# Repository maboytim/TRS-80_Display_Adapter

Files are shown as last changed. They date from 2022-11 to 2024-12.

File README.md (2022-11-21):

# TRS-80_Display_Adapter
Display board and CRT replacement for TRS-80 Models 3 and 4 and the big Tandy's.

### Overview

The adapter board connects to where the the display board normally connects.  It converts the video signals to HDMI or VGA so a modern monitor can be used instead of the builtin CRT.  The adapter uses a low cost (~$15) Nano-9k FPGA module.

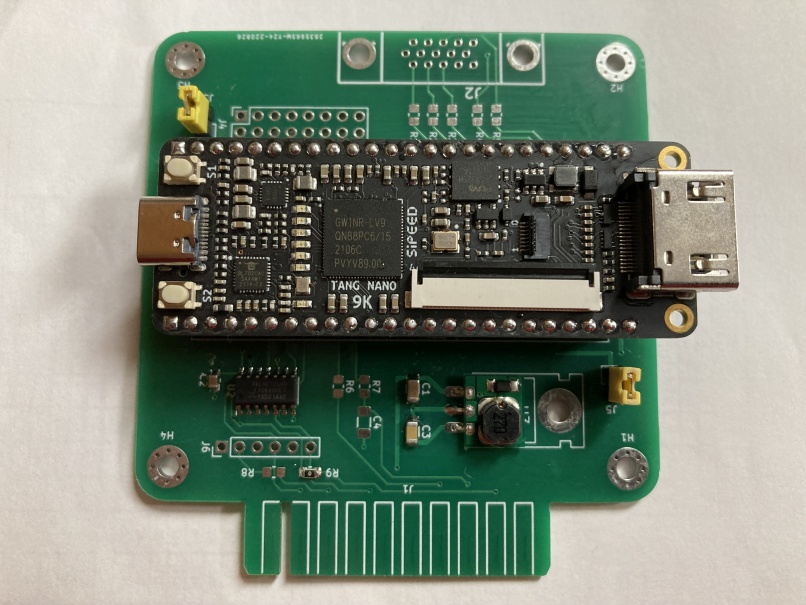
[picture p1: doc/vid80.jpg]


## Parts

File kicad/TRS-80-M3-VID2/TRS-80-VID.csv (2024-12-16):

Reference | Value | Description | Comment
C1 | 10u | 1206
C2 | 0.1uF | 0805
C3 | 1u | 1206
C4 | 1u | 1206 | DNP
J2 | VGA | DB15_Female_HighDensity | Only for VGA out - DMP otherwise.
J3 | 1x2 header |  | Test jumper
J4 | 2x8 header |  | Optional
J5 | 1x2 header | Place shorting block for 5V power from regulator, remove if connecting to USB.
J6 | 1x6 header | For direct cable connection - DNP if not used.
R1 | 200 | 0805 | Only for VGA out - DNP otherwise.
R2 | 200 | 0805 | Only for VGA out - DNP otherwise.
R3 | 200 | 0805 | Only for VGA out - DNP otherwise.
R4 | 200 | 0805 | Only for VGA out - DNP otherwise.
R5 | 200 | 0805 | Only for VGA out - DNP otherwise.
R6 | 1k | 0805 | DNP
R7 | 1k | 0805 | DNP
R8 | 0 | 0805 | Place either R8 or R9 to connect video signal.
R9 | 0 | 0805 | Place either R9 or R8 to connect video signal.
U1 | Tango_Nano_9K
U1 | 24 pin SIP socket | https://www.amazon.com/gp/product/B07GNZQ3ZY or equivalent | Cut to length.
U2 | SO14 | 74LVC125
U3 | L7805 | Regulator | With suitable heatsink. DC-DC converter recommended instead.
U3 | Digikey K7805-500R3-LB | DC-DC replacement for 7805.

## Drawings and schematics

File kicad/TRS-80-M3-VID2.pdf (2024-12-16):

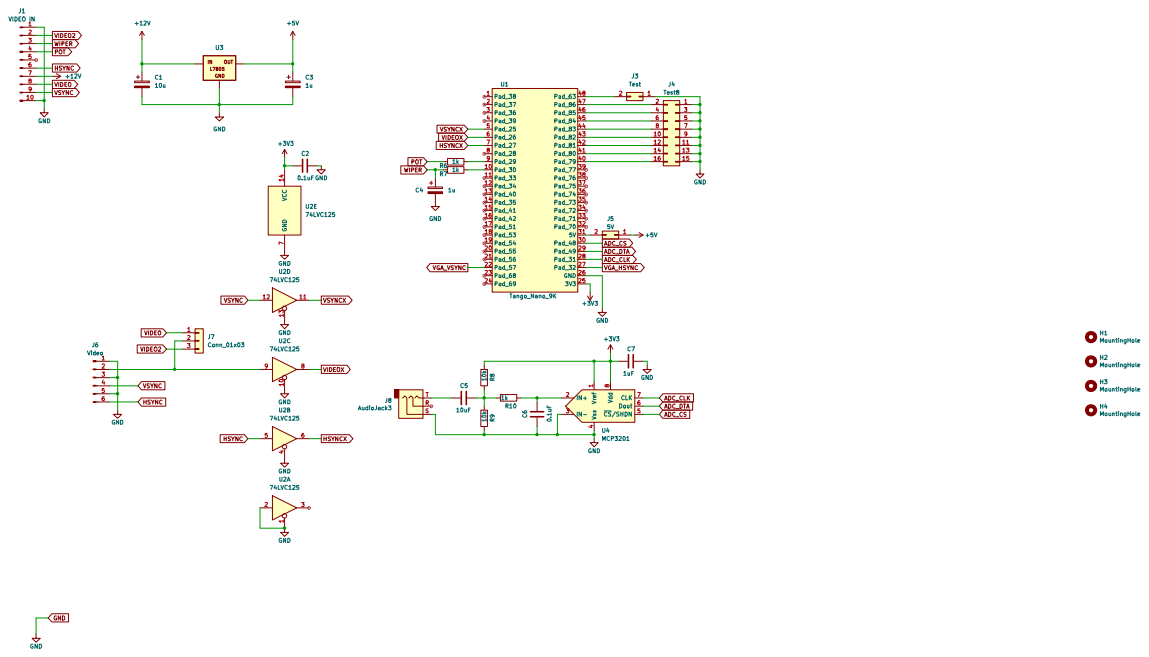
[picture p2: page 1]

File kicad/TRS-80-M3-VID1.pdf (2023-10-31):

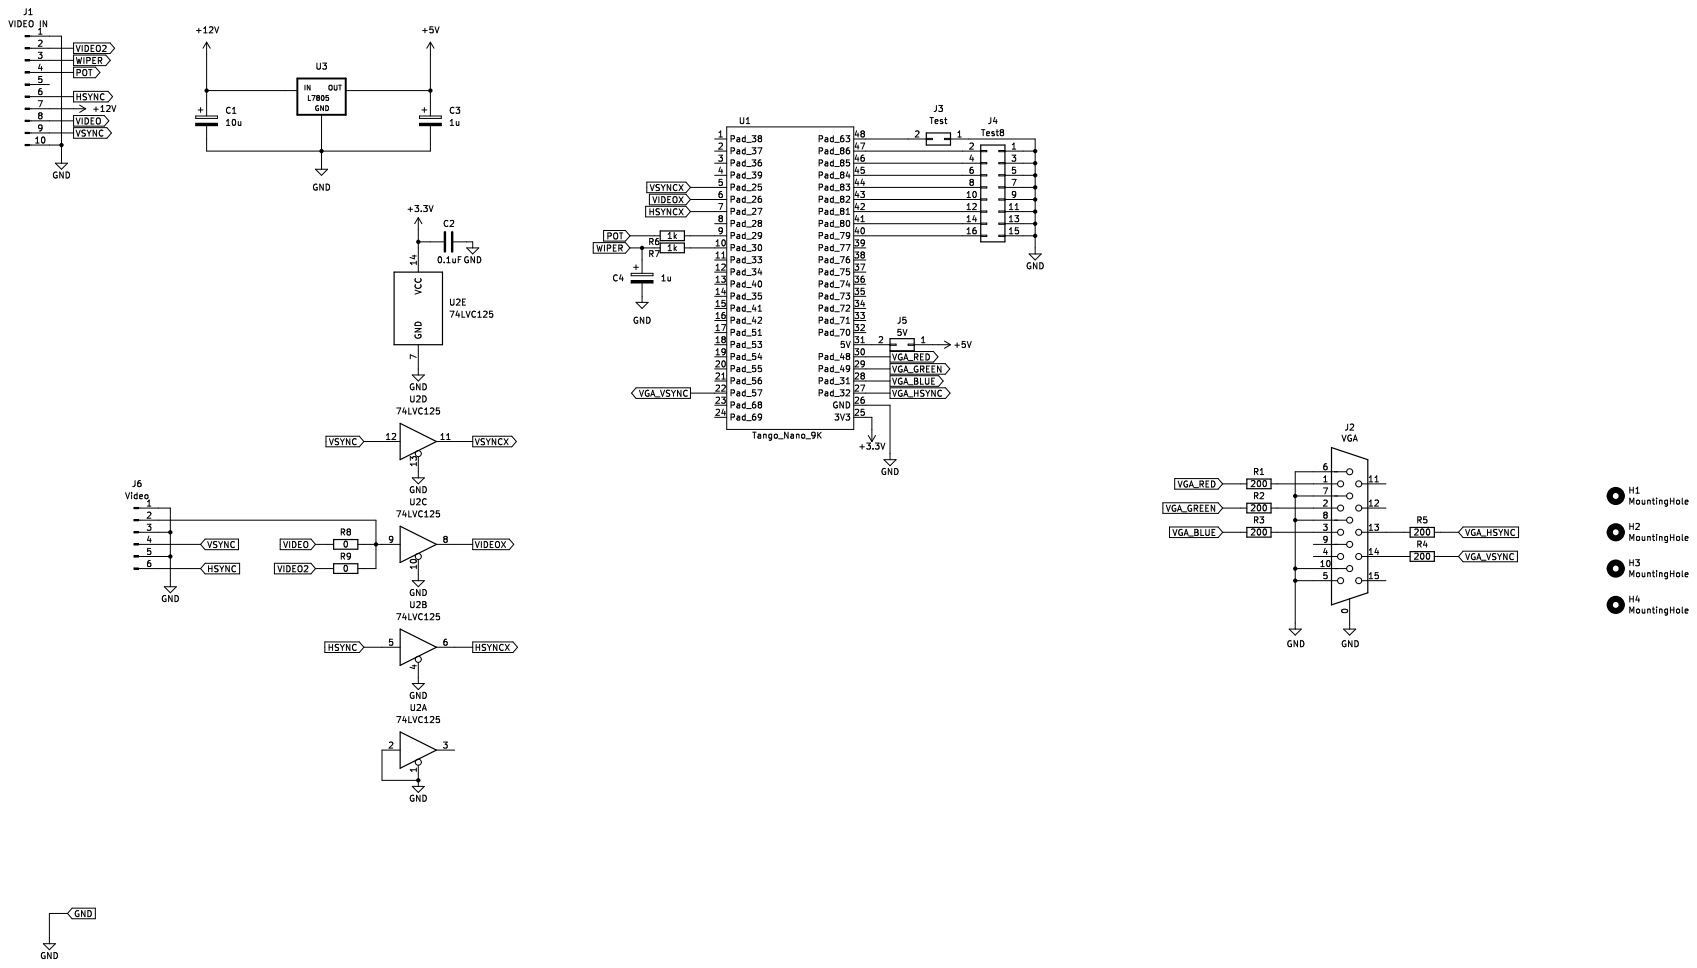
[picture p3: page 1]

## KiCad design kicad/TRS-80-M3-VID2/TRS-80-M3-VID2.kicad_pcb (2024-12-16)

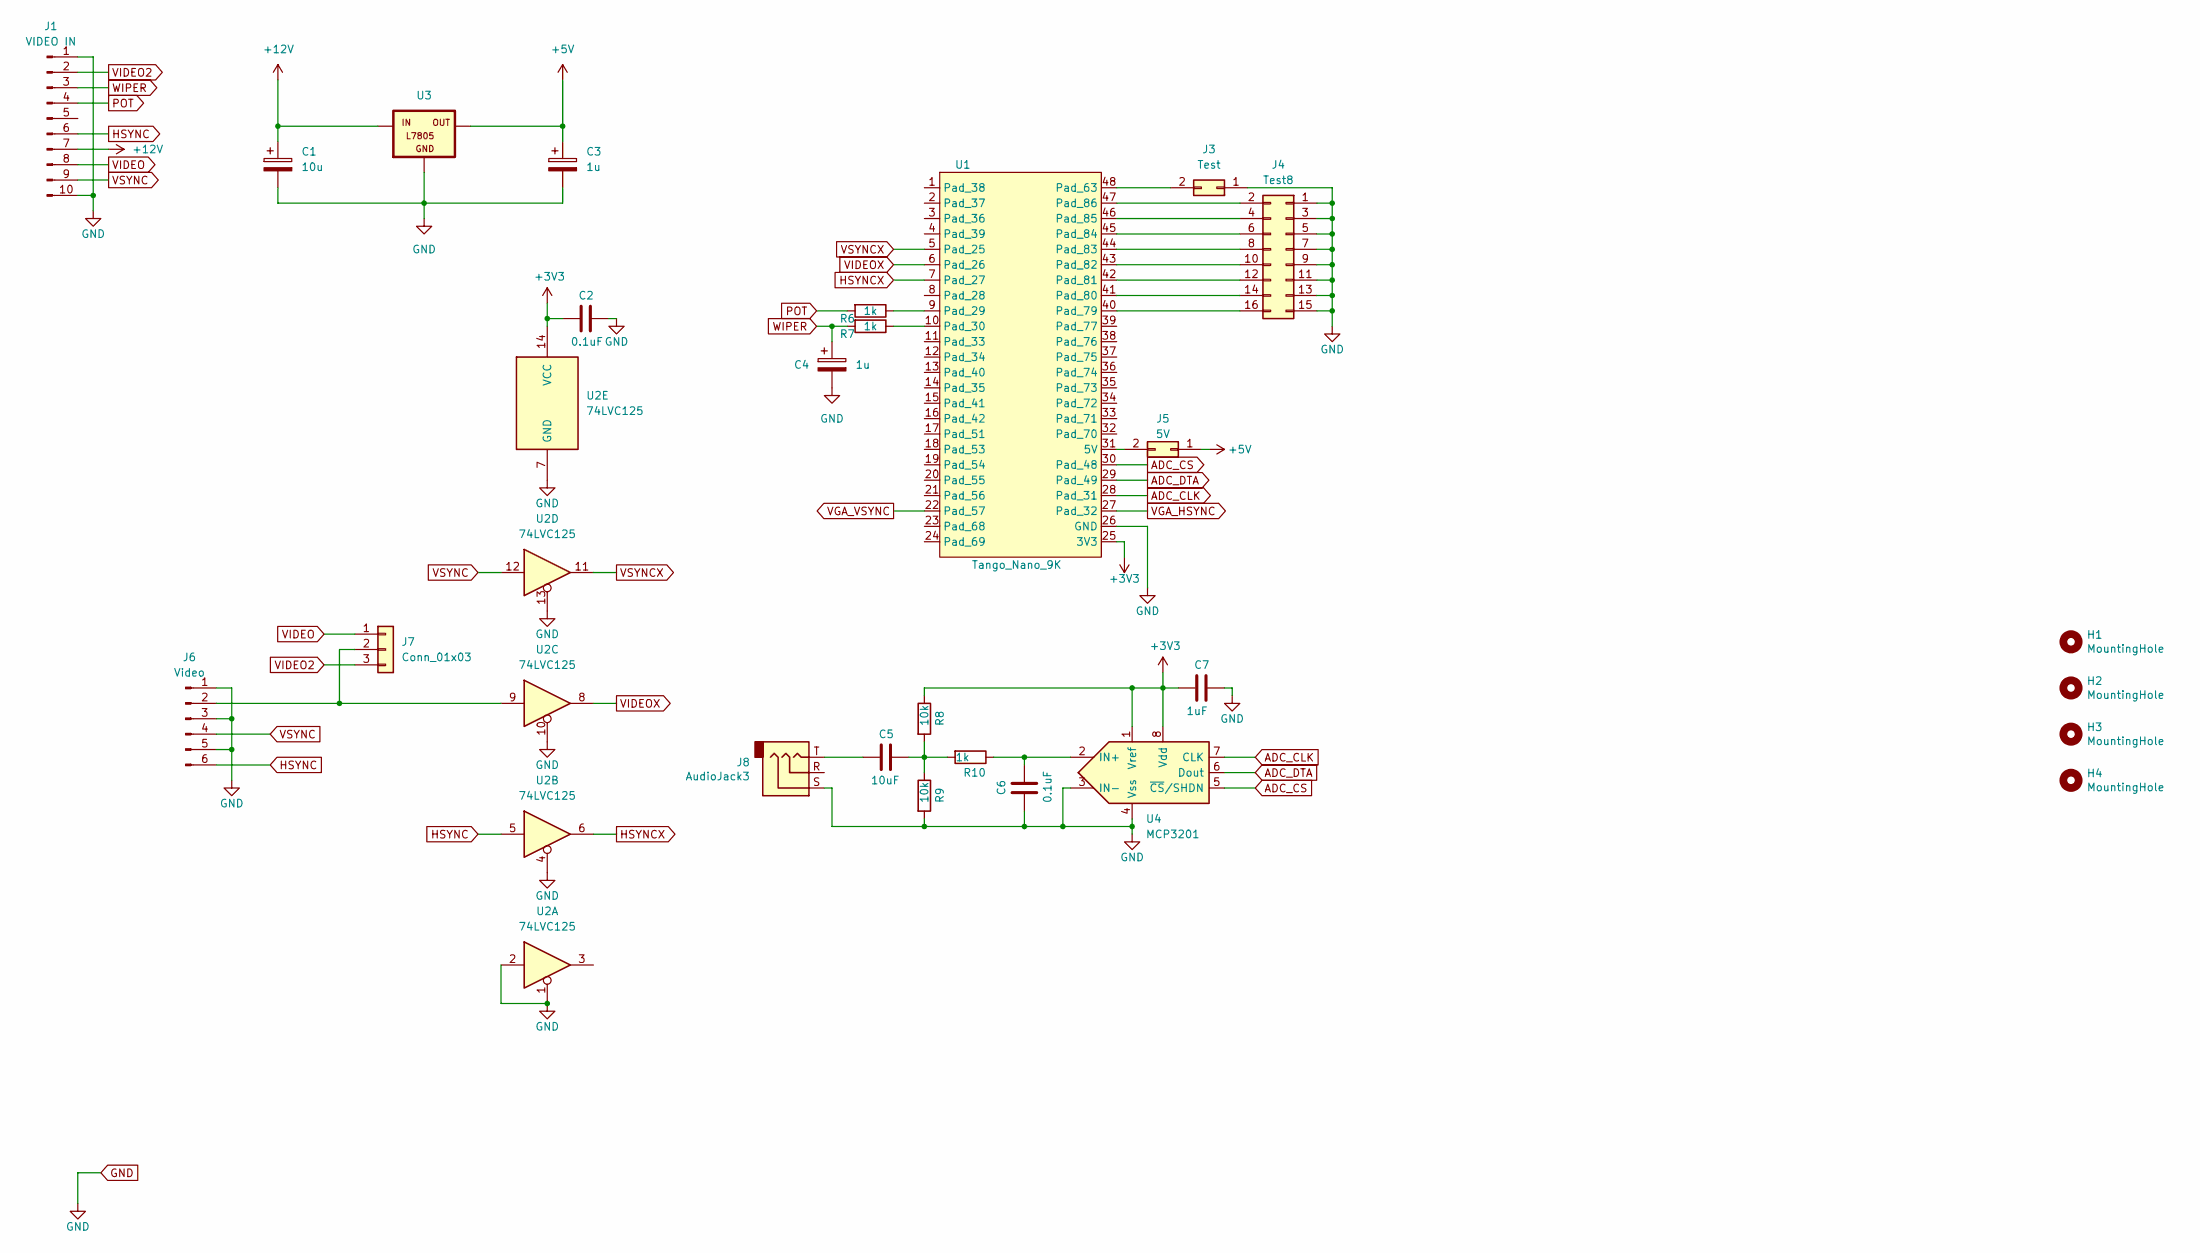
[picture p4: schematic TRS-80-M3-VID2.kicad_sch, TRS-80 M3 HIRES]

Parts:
C1: 10u; C_1206_3216Metric_Pad1.33x1.80mm_HandSolder
C2, C6: 0.1uF; C_0805_2012Metric_Pad1.18x1.45mm_HandSolder
C3, C4: 1u; C_1206_3216Metric_Pad1.33x1.80mm_HandSolder
C5: 10uF; C_0805_2012Metric_Pad1.18x1.45mm_HandSolder
C7: 1uF; C_0805_2012Metric_Pad1.18x1.45mm_HandSolder
H1, H2, H3, H4: MountingHole; MountingHole_3mm_Pad_Via
J1: VIDEO IN; TRSVID10
J3: Test; PinHeader_1x02_P2.54mm_Vertical
J4: Test8; PinSocket_2x08_P2.54mm_Vertical
J5: 5V; PinHeader_1x02_P2.54mm_Vertical
J6: Video; PinHeader_1x06_P2.54mm_Vertical
J7: Conn_01x03; PinHeader_1x03_P2.54mm_Vertical
J8: AudioJack3; Jack_3.5mm_CUI_SJ1-3535NG_Horizontal
R6, R7, R10: 1k; R_0805_2012Metric_Pad1.20x1.40mm_HandSolder
R8, R9: 10k; R_0805_2012Metric_Pad1.20x1.40mm_HandSolder
U1: Tango_Nano_9K; DIP-48_W22.9mm
U2: 74LVC125; SO-14_3.9x8.65mm_P1.27mm
U3: L7805; 78XXL
U4: MCP3201; SOIC-8_3.9x4.9mm_P1.27mm

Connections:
+3V3: C2.2, C7.2, R8.1, U1.25 (3V3), U2.14 (VCC), U4.1 (Vref), U4.8 (Vdd)
+5V: C3.1, J5.1, U3.OUT
+12V: C1.1, J1.7, U3.IN
ADC_CLK: U1.28 (Pad_31), U4.7 (CLK)
ADC_CS: U1.30 (Pad_48), U4.5 (~CS/SHDN)
ADC_DTA: U1.29 (Pad_49), U4.6 (Dout)
GND: C1.2, C2.1, C3.2, C4.2, C6.2, C7.1, J1.1, J1.10, J3.1, J4.1, J4.3, J4.5, J4.7, J4.9, J4.11, J4.13, J4.15, J6.1, J6.3, J6.5, J8.S, R9.2, U1.26 (GND), U2.1, U2.2, U2.4, U2.7 (GND), U2.10, U2.13, U3.GND, U4.3 (IN-), U4.4 (Vss)
HSYNC: J1.6, J6.6, U2.5
HSYNCX: U1.7 (Pad_27), U2.6
unnamed: C5.1, R8.2, R9.1, R10.2
unnamed: C5.2, J8.T
unnamed: J3.2, U1.48 (Pad_63)
unnamed: J4.2, U1.47 (Pad_86)
unnamed: J4.4, U1.46 (Pad_85)
unnamed: J4.6, U1.45 (Pad_84)
unnamed: J4.8, U1.44 (Pad_83)
unnamed: J4.10, U1.43 (Pad_82)
unnamed: J4.12, U1.42 (Pad_81)
unnamed: J4.14, U1.41 (Pad_80)
unnamed: J4.16, U1.40 (Pad_79)
unnamed: J5.2, U1.31 (5V)
unnamed: J6.2, J7.2, U2.9
unnamed: R6.1, U1.9 (Pad_29)
unnamed: R7.1, U1.10 (Pad_30)
unnamed: C6.1, R10.1, U4.2 (IN+)
POT: J1.4, R6.2
VGA_HSYNC: U1.27 (Pad_32)
VGA_VSYNC: U1.22 (Pad_57)
VIDEO: J1.8, J7.1
VIDEO2: J1.2, J7.3
VIDEOX: U1.6 (Pad_26), U2.8
VSYNC: J1.9, J6.4, U2.12
VSYNCX: U1.5 (Pad_25), U2.11
WIPER: C4.1, J1.3, R7.2

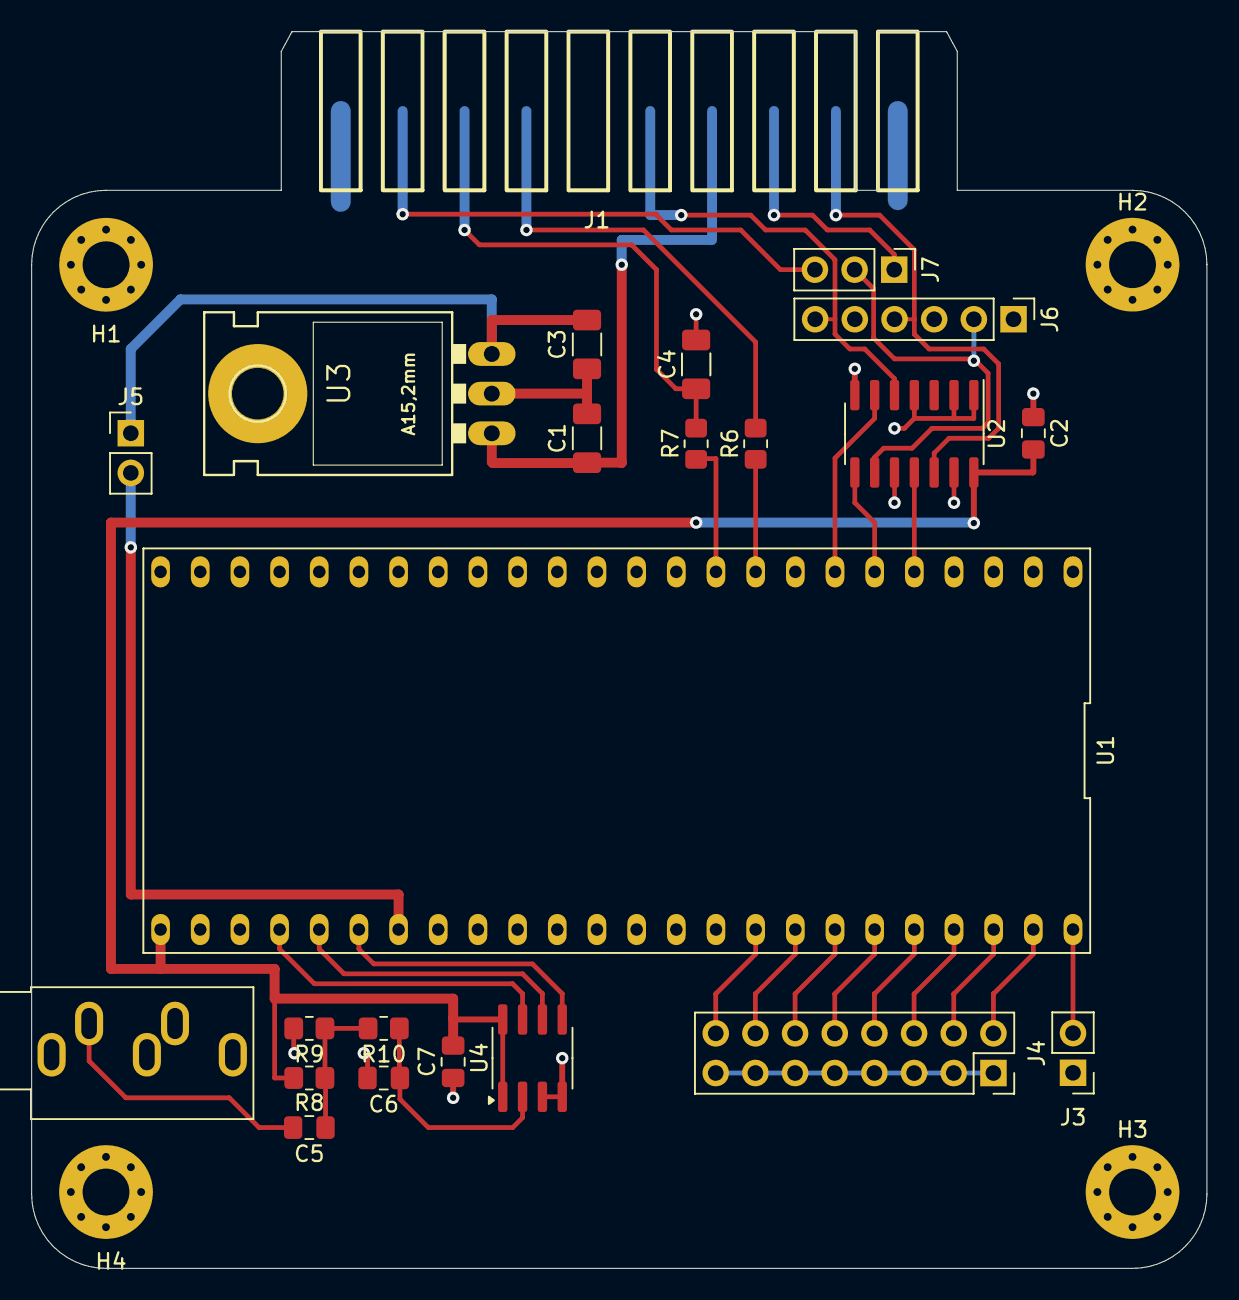
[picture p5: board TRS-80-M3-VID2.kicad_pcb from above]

Board: 2 copper layers, 75.2 x 79.2 mm, 27 parts (0 on the bottom side), 32 nets.

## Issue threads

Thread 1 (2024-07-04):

Video text color

telanoc, 2024-07-04:
It would be incredibly nice if maybe one or two pairs on the row of jumpers was put to use to give green or amber video.  It's the only thing I can think of that might be "wrong" with your board.  Is there room in the chip for such a thing?

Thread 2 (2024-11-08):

Verilog compilation issues

arch-linux, 2024-11-08:
Hello! @maboytim,

I had the boards made, and I am attempting to write the FPGA, I am using VSCODE to compile your FPGA code.

Using this guide [here](https://learn.lushaylabs.com/getting-setup-with-the-tang-nano-9k/)

I am having issues compiling due to a few issues. I am getting the feeling maybe you used a different toolkit or different software entirely for this.

`Processing vis80.lushay.json
Starting FPGA Toolchain
Starting Yosys CST Checking
     /----------------------------------------------------------------------------\
     |  yosys -- Yosys Open SYnthesis Suite                                       |
     |  Copyright (C) 2012 - 2024  Claire Xenia Wolf <claire@yosyshq.com>         |
     |  Distributed under an ISC-like license, type "license" to see terms        |
     \----------------------------------------------------------------------------/
    Parsing gowin_clkdiv.v
        - Module Gowin_CLKDIV parsed
    Parsing gowin_dpb.v
        - Module Gowin_DPB parsed
    Parsing gowin_rpll.v
        - Module Gowin_rPLL parsed
    Parsing BUFG.v
        - Module BUFG parsed
    Error: /Users/archlinuxusa/Downloads/TRS-80_Display_Adapter-main/fpga/vid80-3/src/top.v:47: ERROR: syntax error, unexpected ';', expecting '(' or '['
    Check lines 46-47 of file top.v you may be missing a semicolon or left a block open
Finished CST Checking
Task finished with errors exiting
Toolchain Completed
`

Could you share what you used to program the TANG Nano 9k?
Did you use the VSCODE Chain of tools or  GOWIN?

Thank you very much.

maboytim, 2024-11-09:
Hi,
I use the Gowin IDE.  I've not tried the open source tools.
There are two versions of the Gowin IDE - a full version and a free educational version.  I use the free educational version.
From your errors it looks like the compiler is having trouble with the Gowin IP blocks.  Since I don't know the open source tools I can't help you with that but you might ask someone in that community for help.  These blocks are really hard IP's to access resources on the chip like PLL's and BRAMs.
You shouldn't have to compile though unless you want to make changes.  The .fs programming file is in the impl/pnr folder which is all you really need.  I have used the openFPGALoader which works.  There is also a standalone programmer available from Gowin.  You can program to SRAM but that is volatile and will be lost if you cycle power.  To be persistent you need to program the embedded flash.
If you have any problems feel free to email me directly at ***@***.***
Matt

    On Friday, November 8, 2024 at 06:06:06 PM EST, Christopher Allen ***@***.***> wrote:

Hello! @maboytim,

I had the boards made, and I am attempting to write the FPGA, I am using VSCODE to compile your FPGA code.

Using this guide here

I am having issues compiling due to a few issues. I am getting the feeling maybe you used a different toolkit or different software entirely for this.

Processing vis80.lushay.json Starting FPGA Toolchain Starting Yosys CST Checking /----------------------------------------------------------------------------\ | yosys -- Yosys Open SYnthesis Suite | | Copyright (C) 2012 - 2024 Claire Xenia Wolf ***@***.***> | | Distributed under an ISC-like license, type "license" to see terms | \----------------------------------------------------------------------------/ Parsing gowin_clkdiv.v - Module Gowin_CLKDIV parsed Parsing gowin_dpb.v - Module Gowin_DPB parsed Parsing gowin_rpll.v - Module Gowin_rPLL parsed Parsing BUFG.v - Module BUFG parsed Error: /Users/archlinuxusa/Downloads/TRS-80_Display_Adapter-main/fpga/vid80-3/src/top.v:47: ERROR: syntax error, unexpected ';', expecting '(' or '[' Check lines 46-47 of file top.v you may be missing a semicolon or left a block open Finished CST Checking Task finished with errors exiting Toolchain Completed

Could you share what you used to program the TANG Nano 9k?
Did you use the VSCODE Chain of tools or GOWIN?

Thank you very much.

—
Reply to this email directly, view it on GitHub, or unsubscribe.
You are receiving this because you were mentioned.Message ID: ***@***.***>

arch-linux, 2024-11-09:
@maboytim
Myth Confirmed!

After following your info, I got this going and it works flawlessly.
Thank you very much.

I have 9 other boards that I could potentially populate and produce. Before making any decisions, I wanted to confirm with your unlicense in the github that there are no issues with me selling the remaining PCBs. I want to respect your hard work.

Its also acceptable if you want to speak about this over email - let me know and ill provide mine.

Respectfully

maboytim, 2024-11-13:
I think when you create a project github makes you pick a license.  I tried to pick the most permissive license.  I certainly appreciate your concern of the developer but all of my projects are completely free to do with whatever you want with no credit to me whatsoever.  I'm glad you got it working.  Try PM'ing me for my email.
Matt
    On Friday, November 8, 2024 at 08:54:35 PM EST, Christopher Allen ***@***.***> wrote:

@maboytim
Myth Confirmed!

After following your info, I got this going and it works flawlessly.
Thank you very much.

I have 9 other boards that I could potentially populate and produce. Before making any decisions, I wanted to confirm with your unlicense in the github that there are no issues with me selling the remaining PCBs. I want to respect your hard work.

Its also acceptable if you want to speak about this over email - let me know and ill provide mine.

Respectfully

—
Reply to this email directly, view it on GitHub, or unsubscribe.
You are receiving this because you were mentioned.Message ID: ***@***.***>

Closed 2024-11-10.

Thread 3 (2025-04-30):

Model 1 Support

kiwisincebirth, 2025-04-30:
Would it be possible to adapt this to a TRS-80 Model 1 Computer. Basically a model 1 shares a very similar video display. The primary difference I understand is the DOT clock is lower on the Model 1 since the raster size is 384 / 192, compared to 512 / 192 on the model 3. but the majority of the video circuitry (and signals) are the same.

Apart from maybe a slightly more generic board design. What would it take from a software perspective?

kiwisincebirth, 2025-04-30:
I take it all back I just spotted that you have introduced some support for this. Just didnt see it on the main readme.doc.

maboytim, 2025-05-01:
Besides the resolution the main difference is the M1 video is composite which requires a sync separator to obtain the sync signals.  The M1 sync's are generated using some 74C chips which are used essentially as analog circuits consequently the M1 video isn't real stable.  Consequently it's better to get the sync's directly from the digital circuits.  The M1 video connector conveniently has two unused pins that you can jumper the syncs to.  My idea then was to make a small PCB that buffers the signals and outputs them on a 6-pin connector that's directly compatible with the 6-pin connector on the video adapter board.  I thought I designed the interface board but I don't see it in my kicad folder.  I will do it in the next few days and order it from Oshpark.

kiwisincebirth, 2025-05-01:
Thanks for the response. I came across the project when i was searching for a way to improve the output of my custom built Model 1 - https://github.com/kiwisincebirth/TRS-80-MODEL-1-K/tree/main

It is based on the Japanese Model 1, which has a quite different video generation. (a) The timing dividers have been improved to correctly handle the PAL region (which i live) 625 lines/frame 50Hz, by adding additional lines in the vertical blanking interval. (b) the hsync/vsync generation (original rc delay line with trimpots) has been replaced with digital logic based on the counters eliminating all the horizontal instability.

Unfortunately due to availability I have used a 10.700 Mhz main crystal, so this introduces a .5% variance.  In practice I have found the video output to be rock steady, but the generic Amazon composite to HDMI adapter doesn't do a great job and you are just left with a fuzzy image. A modern TV does a better job but the image if off centre (to right) which is quite annoying, and I am not inclined to use this in front of a large TV

I am not sure how easily it would be to adapt to my build, I haven't done any FPGA development which is probably the limiting factor.

(And off topic) I was also interested in the idea of replicating the entire video chain and getting FPGA or RP2040 to sniff the main address data bus, generating the raster and bit bang a VGA/HDMI signal, there are a couple of Apple 2 products that do just this, which gains you a lot of flexibility, but I am on the fence about emulating hardware. Any thoughts ?

maboytim, 2025-05-01:
It shouldn't be hard to adapt it to your build. It's just a matter of changing counters to match your counters and setting the nominal frequency of the numeric oscillator in the digital PLL. I don't know how the M1 normally does 50Hz but the M3 just adds inactive lines as you described. My design is embedded in the TRS-IO for the M3 and it supports the 60Hz and 50Hz modes of the M3.

There are a number of devices that mirror the M1 video by snooping on the bus - the TRS-IO for M1, TRS-IO++ in TRS-IO-M1 mode, the M1RE by Bartlett Labs, and probably others. If your expansion port is the same as the normal M1 then any of these should work and mirror the video. Or you can easily make your own. If you don't care about taking the video from the normal output this is probably the easiest way. The TRS-IO's also emulate LE-18 hires graphics and I suspect the M1RE does too, and have many more features.

If you're making your own, using a dual-port RAM makes it a lot easier which you can get in the small 1k size although expensive. The FPGA's have dual-port RAM.

Matt
     On Wednesday, April 30, 2025 at 09:44:58 PM EDT, Mark Pruden ***@***.***> wrote:

 kiwisincebirth left a comment (maboytim/TRS-80_Display_Adapter#3)
Thanks for the response. I came across the project when i was searching for a way to improve the output of my custom built Model 1 - https://github.com/kiwisincebirth/TRS-80-MODEL-1-K/tree/main

It is based on the Japanese Model 1, which has a quite different video generation. (a) The timing dividers have been improved to correctly handle the PAL region (which i live) 625 lines/frame 50Hz, by adding additional lines in the vertical blanking interval. (b) the hsync/vsync generation (original rc delay line with trimpots) has been replaced with digital logic based on the counters eliminating all the horizontal instability.

Unfortunately due to availability I have used a 10.700 Mhz main crystal, so this introduces a .5% variance. In practice I have found the video output to be rock steady, but the generic Amazon composite to HDMI adapter doesn't do a great job and you are just left with a fuzzy image. A modern TV does a better job but the image if off centre (to right) which is quite annoying, and I am not inclined to use this in front of a large TV

I am not sure how easily it would be to adapt to my build, I haven't done any FPGA development which is probably the limiting factor.

(And off topic) I was also interested in the idea of replicating the entire video chain and getting FPGA or RP2040 to sniff the main address data bus, generating the raster and bit bang a VGA/HDMI signal, there are a couple of Apple 2 products that do just this, which gains you a lot of flexibility, but I am on the fence about emulating hardware. Any thoughts ?

—
Reply to this email directly, view it on GitHub, or unsubscribe.
You are receiving this because you commented.Message ID: ***@***.***>

kiwisincebirth, 2025-05-08:
Thanks for your detailed reply:

Just to clarify the Model-1 (Japan version) borrows a lot from the Model 3 in terms of 50Hz generation. There are differences, but mostly timing related to the different DOT clock that is used.

I did some reading on TRS-IO (classic) and it looks very interesting, and possibly quite good for my needs. I am building a FreHD presently, so will consider it in future.

I think you should close this (non issue) now. I have just joined Discord server, so can ask questions there. :)

Closed 2025-07-13.

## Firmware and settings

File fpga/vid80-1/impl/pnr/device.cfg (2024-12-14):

set JTAG regular_io = false
set SSPI regular_io = false
set MSPI regular_io = false
set READY regular_io = false
set DONE regular_io = false
set I2C regular_io = false
set RECONFIG_N regular_io = false
set CRC_check = true
set compress = true
set encryption = false
set security_bit_enable = true
set bsram_init_fuse_print = true
set background_programming = off
set secure_mode = false
set program_done_bypass = false
set wake_up = 0
set format = binary
set power_on_reset_monitor = true
set multiboot_spi_flash_address = 0x00000000
set vccx = 3.3
set unused_pin = default

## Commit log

2023-10-31 Added kicad project.
    [TRS-80-M3-VID1-B_Cu.gbr, TRS-80-M3-VID1-B_Mask.gbr, TRS-80-M3-VID1-B_Silkscreen.gbr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]
2023-10-31 Added pdf schematic.
2023-12-14 Added FPGA files for M3 version
    [device.cfg]
2023-12-16 Added FPGA files for M4 version
    [device.cfg]
2024-03-01 Added FPGA design for Big Tandy version.
    [device.cfg]
2024-07-09 Added selection of 4 colors using two jumpers.
    [device.cfg]
2024-12-14 Added FPGA design for Model 1 version.
    [device.cfg]
2024-12-16 Added hardware support for cassette input to HDMI audio output.
    [TRS-80-M3-VID2-B_Cu.gbr, TRS-80-M3-VID2-B_Mask.gbr, TRS-80-M3-VID2-B_Silkscreen.gbr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]
